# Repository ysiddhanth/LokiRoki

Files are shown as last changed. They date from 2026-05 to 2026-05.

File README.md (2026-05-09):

# LokiRoki

> [!NOTE]
> ## Project Status
>
> ### PCB Build
> - Fabrication completed
> - Components still need to be sent to the assembly company
>
> ### 3D Modeling
> - Initial work has begun
> - Files have not yet been uploaded
>
> ### Programming
> - Awaiting procurement of LoRa modules
> - Firmware testing to begin after hardware arrives

## Application / Problem Statement

Conventional walkie-talkies operate over licensed FM/VHF/UHF bands, which are subject to regulatory constraints, interference from other users, and limited range in urban environments. They are also typically bulky and expensive.

At the same time, consumer-grade Bluetooth and Wi-Fi radios offer only short-range communication and usually require existing infrastructure.

There exists a clear need for a low-cost, long-range, license-free voice communication device suitable for scenarios such as:

- Outdoor activities (hiking, camping, field operations) where cellular coverage is unavailable.
- Campus or community communications without reliance on mobile networks.
- Emergency or off-grid communication links requiring robust, low-power operation.

The proposed device targets ranges of:

- **2–5 km** in urban areas
- **Up to 15 km** in open terrain

The system operates entirely within the **license-exempt 865–868 MHz band in India**.

---

## Proposed Solution

The solution is a self-contained, push-to-talk (PTT) walkie-talkie based on the **LoRa (Long Range)** radio protocol, with onboard speech compression using **Codec 2**.

Two identical units will be built, each capable of:

- Transmitting voice
- Receiving voice
- Operating independently without cellular or internet infrastructure

---

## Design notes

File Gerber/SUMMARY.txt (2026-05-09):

TopCopper:1
BottomCopper:1
TopSolderMask:1
BottomSolderMask:1
TopSilkScreen:1
BottomSilkScreen:1
BoardOutline:1
DrillFile1:1
DrillFile2:1

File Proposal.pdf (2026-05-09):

LoRa Push-to-Talk Walkie Talkie | EE3900 – Project Proposal

# LoRa Push-to-Talk Walkie Talkie

### Project Proposal

Team Members: S A Aravind Eswar (EE24BTECH11053) Siddhanth Y (EE24BTECH11059)

Date: March 2026

### Application / Problem Statement

Conventional walkie-talkies operate over licensed FM/VHF/UHF bands, which are subject to regulatory constraints, interference from other users, and limited range in urban environments. They are also typically bulky and expensive. At the same time, consumergrade Bluetooth and Wi-Fi radios offer short range and require existing infrastructure.

There exists a clear need for a low-cost, long-range, license-free voice communication device suitable for scenarios such as:

- Outdoor activities (hiking, camping, field operations) where cellular coverage is unavailable.
- Campus or community communications without reliance on mobile networks.
- Emergency or off-grid communication links requiring robust, low-power operation.

The proposed device targets ranges of 2–5 km in urban areas and up to 15 km in open terrain, operating entirely within the licence-exempt 865–868 MHz band in India.

### Proposed Solution

The solution is a self-contained, push-to-talk (PTT) walkie-talkie based on the LoRa (Long Range) radio protocol, with onboard speech compression via Codec 2. Two identical units will be built, each capable of transmitting and receiving voice.

System Architecture

The signal chain for transmission is:

Microphone → ESP32 (Codec 2 Encode) → LoRa Module (TX) → Antenna

And for reception:

Antenna → LoRa Module (RX) → ESP32 (Codec 2 Decode) → Class-D Amplifier → Speaker

Key Technology Choices

LoRa Radio – RYLR998 Module
LoRa (Long Range) is a low-power wide-area modulation scheme well suited to battery-operated embedded devices. The RYLR998 operates in the 868/915 MHz band, supports output power up to +22 dBm, and achieves a receive sensitivity of −129 dBm, enabling multi-kilometre links with very modest transmit power. At the Codec 2 bitrates used (450–3200 bps), the available LoRa air-data rate is more than sufficient.

Microcontroller – ESP32-WROOM-32
The ESP32 is a dual-core 240 MHz processor with adequate computational headroom to run real-time Codec 2 encoding and decoding. It communicates with the LoRa module over SPI and with the I2S microphone directly over the I2S bus, eliminating the need for an external ADC.

Speech Codec – Codec 2
Codec 2 is an open-source, low-bitrate speech codec specifically designed for voice over narrow-band radio links. At 1200 bps it produces intelligible speech; at 3200 bps the quality is comparable to FM radio. This drastically reduces the amount of data that must be transmitted over the LoRa link.

Audio Front-End
An I2S MEMS microphone provides digital audio directly to the ESP32 with a 60– 65 dB SNR and no analogue amplification stage. On the output side, a PAM8403 Class-D amplifier (up to 3W into 4 Ω, ∼85% efficient) drives an 8 Ω speaker.

Power System
The PCB design implements a lithium-ion battery management and protection circuit (BQ21040 charger, BQ29700 protection) alongside two TPS6300x buck-boost converters, producing regulated 5 V and 3.3 V rails from the battery. USB-C (USB4085-GF-A receptacle) is used for charging. A CP2102 USB-to-UART bridge enables firmware flashing.

Communication Regulatory Compliance

The device operates in the 865–868 MHz licence-exempt band as defined by WPC India, with transmit power limited to ≤14 dBm to meet CE and regional regulatory requirements, well within the permitted 1W (30 dBm) envelope.

### Practical Feasibility

Component Availability

All components are available through domestic Indian suppliers (primarily robu.in), ensuring short lead times and no import complications. The ESP32-WROOM-32 and PAM8403 are commodity parts stocked by multiple distributors. The RYLR998 LoRa module is a purpose-built transceiver with an AT-command interface, significantly reducing RF development effort.

Cost Effectiveness

The total prototype cost of approximately INR 5000 for one units compares favourably against commercial walkie-talkies with similar range, which typically retail at INR 3,000– 8,000 per unit without the flexibility of open-source firmware or licence-exempt operation.

At scale, the BOM cost would reduce significantly given the commodity nature of most components.

Technical Risk Assessment

Risk | Mitigation | Severity

LoRa bandwidth insufficient for
voice
Codec 2 | compresses | voice | to
<3.2 kbps; | LoRa | supports | up
to 30 kbps

Low

ESP32 too slow for real-time Codec 2 Codec 2 has verified ESP32 ports at 1200–3200 bps

Low

RF regulatory non-compliance | Limit TX power to ≤14 dBm via AT command
Low
Audio latency affecting PTT experi- ence | Codec 2 frame size is 40 ms; accept- able for PTT use
Medium

Table 1: Risk Assessment

Project Timeline

Weeks 1–2: Component procurement and environment setup.
Weeks 3–7: PCB assembly, firmware development, and first prototype testing.
Weeks 8–12: Range testing, design iteration, and final product build. Documentation maintained throughout.

### Competitive Analysis

The table below benchmarks the proposed device against representative products across three market tiers: consumer/budget, mid-range professional, and open-source LoRa alternatives.

Analysis by Tier

Budget tier (INR 2,000–4,000 per pair) – Baofeng UV-5R, Retevis RT22. The Baofeng UV-5R is the dominant budget option globally: inexpensive and capable, but it operates on analogue FM and requires an amateur radio licence to transmit legally in India, making it unsuitable for unlicensed use. The Retevis RT22 is licence-free but limited to short-range analogue UHF with no digital compression, resulting in lower effective range and no path for firmware customisation. Our device enters this tier in cost while significantly outperforming both on range.

Mid-range professional tier (INR 10,000–25,000 per pair) – Motorola XT185. The Motorola XT185 is a polished, IP54-rated PMR446 business radio with up to 24 hours of battery life and a claimed 8 km open-field range. However, in urban conditions its practical range drops to 1–2 km, it is purely analogue, and the pair retails at roughly

Product | TechnologyRange
(Urban /
Open)

Licence
Required

Open
Source

Cost
(pair,
INR )
Our Device (Loki) | LoRa | +
| Codec 2
2–5 km | /
15 km

No (865–
868 MHz
exempt)
Yes | ∼5,600
Baofeng UV-5R | Analogue
FM
VHF/UHF

1–3 km /
5–8 km

Yes (Ham
licence)
No | ∼2,000
Motorola XT185 | Analogue
PMR446

1–2 km /
8 km
No | No | ∼16,000
Retevis RT22 | Analogue
UHF

1–3 km /
5 km
No (licence- free UHF) | No | ∼3,000
LILYGO T3-S3 MVRS | LoRa | +
Codec 2
(dev kit)

2–5 km /
10+ km
No | Yes | ∼4,500
Motorola MOTOTRBO R2 | Digital
DMR
UHF/VHF

3–5 km /
10 km

Yes (business
licence)
No | ∼30,000+

Table 2: Competitive Landscape – representative products across price tiers

INR 16,000–20,000 in India – nearly three times our prototype cost – with no provision for firmware updates or feature extension.

Enterprise tier (INR 30,000+ per pair) – Motorola MOTOTRBO R2. DMR digital radios such as the MOTOTRBO R2 offer superior audio clarity and longer range but mandate a licensed business-band frequency assignment, involve significant recurring regulatory overhead, and are priced far beyond any hobbyist or low-budget deployment scenario.

Open-source LoRa tier – LILYGO T3-S3 MVRS. The LILYGO T3-S3 MVRS is the closest technical analogue to our device: it also uses ESP32 + LoRa + Codec 2 on the same FSK/LoRa modulation at 914.6 MHz. At approximately $27 (INR 2,250) per bare board, two units cost roughly INR 4,500, but the kit ships as a bare development board with no enclosure, no battery management, no charging circuitry, and no push-to-talk hardware – requiring significant additional integration work. Our design integrates all of these elements on a custom PCB.

Key Differentiators

FeatureOur Device Baofeng UV-5R Motorola XT185 LILYGO T3-S3 MOTOTRBO R2

Licence-free
operation
(India)
✓ | × | ✓ | ✓ | ×

Urban
range
>2 km
✓ | ∼ | × | ✓ | ✓

Open-source
firmware
✓ | × | × | ✓ | ×

Integrated
battery
+
USB-C
charging
✓ | × | ✓ | × | ✓

Digital
voice
(noise
resilient)
✓ | × | × | ✓ | ✓

Cost
per
pair
<
INR 8,000
✓ | ✓ | × | ✓ | ×

Productionready
enclosure
– | ✓ | ✓ | × | ✓

Table 3: Feature comparison matrix (✓ = yes, × = no, – = in progress)

In summary, the proposed Loki device occupies a currently vacant position in the market: a licence-free, digitally compressed, long-range, open-source walkie-talkie at a sub-INR 3,000 per-unit cost. No commercially available product combines all four of these attributes simultaneously at this price point.

### Breakdown

Charging

Features current surge protection, smart power switching when charging.

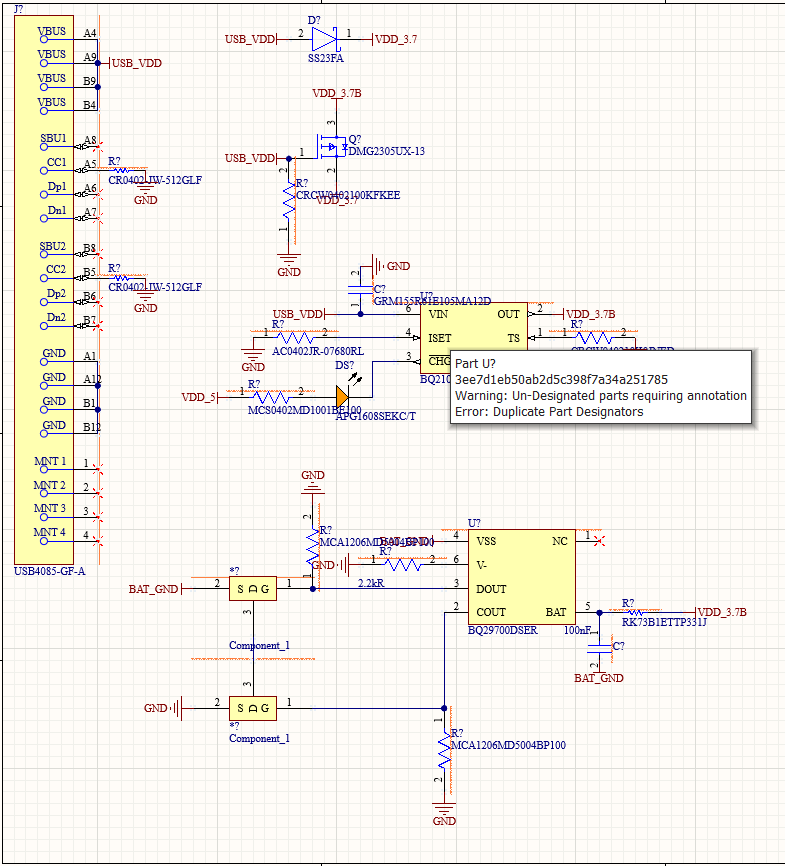
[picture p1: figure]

Uses BQ21040 for charging and BQ29700 for surge protection.

Buck-Boost Converters

Uses Buck-Boost converters for stable constant voltage output.

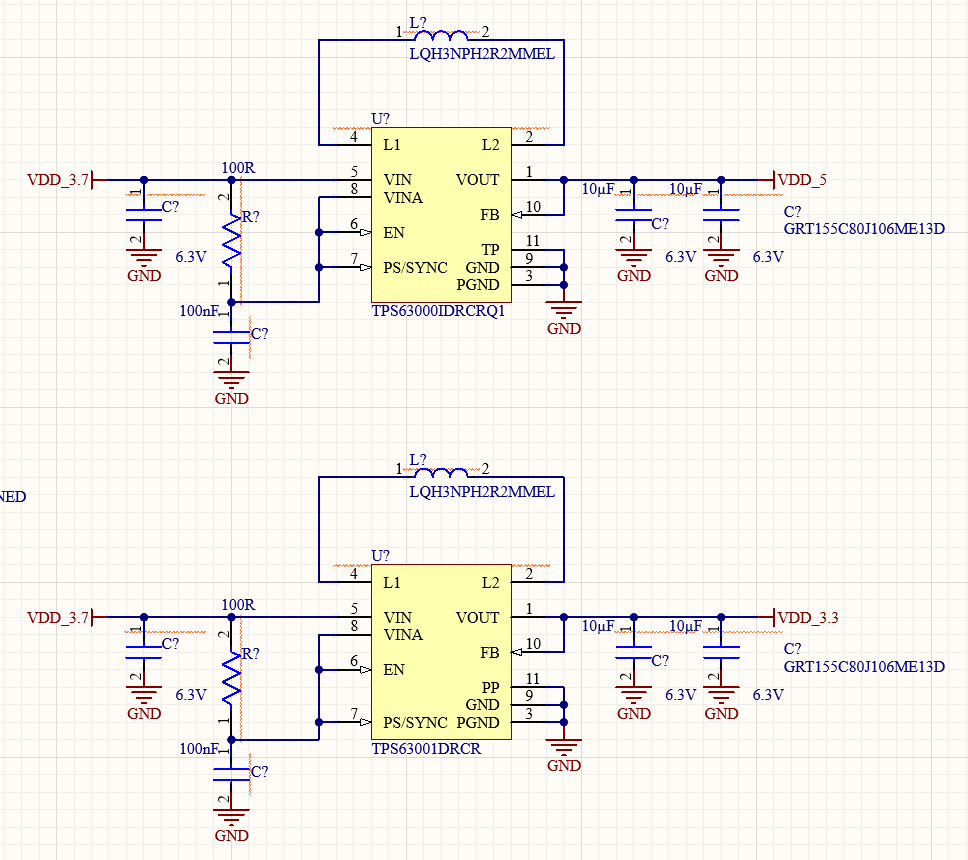
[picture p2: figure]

Figure 1: 5V and 3.3V Buck-Boost converters (top and bottom respectively)

Uses TPS6300X series IC for operation.

### Conclusion

The LoRa PTT walkie-talkie is a technically sound and cost-effective solution to the problem of long-range, infrastructure-independent voice communication. The combination of LoRa’s propagation characteristics, Codec 2’s efficiency, and the ESP32’s processing capability creates a feasible and practical device that can be built entirely from commercially available, domestically sourced components within a modest budget.

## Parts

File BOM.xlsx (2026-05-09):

www.lioncircuits.com No. +91 - 80 4711 2351
Assembly Bill of Materials
PID | 215506
Version | V4.0
Project Name | LokiRoki
Downloaded Date | 2026-05-09 21:12 (IST)
Downloaded By | ee24btech11059@iith.ac.in
Total Line Item | 30
Sl No. | Designator | Description | Quantity | Mpn | Footprint | Value | Assembly Instruction
1 | C102, C104, C105, C106, C108, C109, C202, C203 | CC0402MRX5R5BB106 - YAGEO - MLCC SMD Capacitor - 10 uF, 6.3 V, 0402 [1005 Metric], 20%, X5R, CC Series | 8 | CC0402MRX5R5BB106 | SMD-0402 | 4.53 | N.A
2 | 214, C201, C206, C208, C212, C103, C107, C110 | Yageo 0.1uF 50V 0402 SMD Multilayer Ceramic Capacitor | 8 | Generic | SMD-0402 | 1 | N.A
3 | C204, C205, C210, C211, C213, C101, C111 | 04023D105KAT2A.-KYOCERA AVX-CAP, 1UF, 25V, MLCC, 0402 | 7 | 04023D105KAT2A | SMD-0402 | 3.3 | N.A
4 | R201, R203, R204, R106 | RC0402FR-0710KL-YAGEO-Res Thick Film 0402 10K Ohm 1% 0.063W(1/16W) ±100ppm/°C Pad SMD T/R | 4 | RC0402FR-0710KL | SMD-0402 | 9.38 | N.A
5 | Q201, Q202 | BC817-40W-CBI-SOT-323 Bipolar (BJT) ROHS | 2 | BC817-40W | TO236AB | 3.78 | N.A
6 | Q102, Q103 | N.A | 2 | N.A |  |  | N.A
7 | R107, R108 | RT0402BRD07100RL-YAGEO-Res Thin Film 0402 100 Ohm 0.1% 0.063W(1/16W) ±25ppm/°C Pad SMD T/R | 2 | RT0402BRD07100RL | SMD-0402 | 1.27 | N.A
8 | L101, L102 | SWPA4030S2R2MT-Sunlord-2.2uH 2.95A 20% 39mOhm Shielded Wirewound Power Inductor SMD | 2 | SWPA4030S2R2MT | SMD-1212 | 3.44 | N.A
9 | R110, R112 | Res MC AT Precision Thin Film 1206 5MΩ 0.1% 0.4W ±25ppm/°C Molded Paper T/R | 2 | MCA1206MD5004BP500 | SMD-1206 | 70.33 | N.A
10 | R205, R206, R101, R102 | AC0402FR-075K1L-YAGEO-Res Thick Film 0402 5.1K Ohm 1% 0.063W(1/16W) ±100ppm/°C Pad SMD T/R Automotive AEC-Q20 | 4 | AC0402FR-075K1L | SMD-0402 | 10.31 | N.A
11 | J101, J202 | CONN RCPT USB2.0 TYPE C 24POS RA | 2 | USB4085-GF-A |  | 83.45 | N.A
12 | J201 | Ffc/Fpc Board Connector, Zif, Surface Mount, Plug, 10, Top, 0.5 Mm Rohs Compliant: Yes |Wurth Elektronik 68711014022 | 1 | 68711014022 | 10 Pin FPC Connector | 108.77 | N.A
13 | R104 | 0402WGF6800TCE-Uniohm/Royal-ohm-62.5mW Thick Film Resistors 50V ±100ppm/℃ ±1% 680Ω 0402 Chip Resistor - Surface Mount ROHS | 1 | 0402WGF6800TCE | SMD-0402 | 0.06 | N.A
14 | DS102 | 19-217/G7C-AN1P2/3T-EVERLIGHT-Yellow-Green 574nm LED Indication - Discrete 2V 0603 (1608 Metric) | 1 | 19-217/G7C-AN1P2/3T-EVERLIGHT LED | SMD-0603 | 1 | N.A
15 | U101 | IC BATT CHG LI-ION 1CELL SOT23-6 | 1 | BQ21040DBVR | SOT23-6 | 83.45 | N.A
16 | U104 | IC LITHIUM BATT PROTECT 6-SON | 1 | BQ29700DSER | 6-SON | 5.4 | N.A
17 | U202 | Single-Chip USB to URAT Bridge, 3.3 V, -40 to 85 degC, 28-Pin QFN, RoHS, Tape and Reel | 1 | CP2102-GMR | 28-Pin QFN | 832.66 | N.A
18 | R103 | RC0402FR-07100KL,YAGEO,100 kOhm ±1% 0.063W, 1/16W Chip Resistor 0402 | 1 | RC0402FR-07100KL | SMD-0402 | 0.09 | N.A
19 | Q101 | MOSFET P-CH 20V 4.2A SOT23 | 1 | DMG2305UX-13 | SOT23 | 11 | N.A
20 | MD201 | RX TXRX MOD WIFI SURFACE MOUNT | 1 | ESP32-WROOM-32 |  |  | N.A
21 | C207 | IM02B473K100NT-FH-SMD Multilayer Ceramic Capacitor, 47000 pF(4.7nF), 10 V, 0402 [1005 Metric], ± 10%, X7R | 1 | IM02B473K100NT | SMD-0402 | 9.38 | N.A
22 | C209 | GRT155R71A474KE01D-Murata-Cap Ceramic 0.47uF 10V X7R 10% Pad SMD 0402 125°C Automotive T/R | 1 | GRT155R71A474KE01D | SMD-0402 | 9.38 | N.A
23 | R105 | RC0402FR-071K2L-YAGEO-Res Thick Film 0402 1.2K Ohm 1% 0.063W(1/16W) ±100ppm/°C Pad SMD T/R | 1 | RC0402FR-071K2L | SMD-0402 | 0.08 | N.A
24 | U201 | IC AMP CLASS D STEREO 3W 16SOP | 1 | PAM8403DR | 16-SOIC | 67.51 | N.A
25 | R109 | AC0402FR-072K2L-YAGEO-Res Thick Film 0402 2.2K Ohm 1% 0.063W(1/16W) ±100ppm/°C Pad SMD T/R Automotive AEC-Q200 | 1 | AC0402FR-072K2L | SMD-0402 | 0.07501 | N.A
26 | R111 | CRCW0402330RFKED-VISHAY-SMD Chip Resistor, 330 ohm, ± 1%, 62.5 mW, 0402 [1005 Metric], Thick Film, General Purpose | 1 | CRCW0402330RFKED | SMD-0402 | 0.37 | N.A
27 | R207 | 0402WGJ0470TCE-Uniohm/Royal-ohm-62.5mW Thick Film Resistors 50V±100ppm/℃ ±5% 47Ω 0402 Chip Resistor - Surface Mount ROHS | 1 | 0402WGJ0470TCE | SMD-0402 | 0.03 | N.A
28 | DS101 | NRVBSS34FA Schottky Barrier Rectifier Diode 40V 3A 2-Pin SOD−123FL T/R | 1 | SS34FA | SOD-123FL-2 | 49 | N.A
29 | U102 | Buck-Boost Voltage Converter with 1.8 to 5.5 V Input and 1.2 to 5.5 V Output, -40 to 85 degC, 10-Pin SON (DRC), Green (RoHS & no Sb/Br) | 1 | TPS63000IDRCRQ1 | 10-VFDFN Exposed Pad | 136.06 | N.A
30 | U103 | Buck-Boost Voltage Converter with 1.8 to 5.5 V Input and 3.3 V Output, -40 to 85 degC, 10-Pin SON (DRC), Green (RoHS & no Sb/Br) | 1 | TPS63001DRCR | 10-VFDFN Exposed Pad | 225.89 | N.A

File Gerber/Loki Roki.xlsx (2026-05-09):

Line # | Name | Description | Designator | Revision ID | Revision Status | Quantity | Manufacturer 1 | Manufacturer Part Number 1 | Manufacturer Lifecycle 1 | Supplier 1 | Supplier Part Number 1 | Supplier Unit Price 1 | Supplier Subtotal 1
 | GRT155C80J106ME13D | GRT155C80J106ME13D Multilayer Ceramic Capacitors MLCC - SMD/SMT 0402 10uF 6.3VDC 20% X6S AEC-Q200 | C102, C104, C105, C106, C108, C109 | CMP-00260-136148754-1 | Up to date | 6 | Murata | GRT155C80J106ME13D | Volume Production | DigiKey | 490-GRT155C80J106ME13DCT-ND | 14.82 | 148.15
 | C0402C104K8RAC | C0402 0.10 μF X7R 10.00% 10 V | 214, C201, C206, C208, C212 | CMP-03020-004693-2 | Up to date | 5 | Yageo Group | C0402C104K8RAC | Volume Production | Mouser | 80-C0402C104K8RAC | 0.56261 | 5626.07
 | GRM155C81C105ME11J | Chip Multilayer Ceramic Capacitors for General Purpose, 0402, 1.0uF, X6S, 22%, 20%, 16V | C204, C205, C210, C211, C213 | CMP-06035-050604-1 | Up to date | 5 | Murata | GRM155C81C105ME11J | Volume Production | Mouser | 81-GRM155C81C105ME1J | 3.75 | 37.51
 | 560112110006 | Res, 10K, 5%, 0.1W, Thick Film, 0402 Rohs Compliant: Yes | R201, R203, R204 | CMP-03913-145532690-1 | Up to date | 3 | Wurth Elektronik | 560112110006 | Unknown | Mouser | 710-560112110006 | 9.38 | 28.13
 | GRM155R71H104ME14D | Chip Multilayer Ceramic Capacitors for General Purpose, 0402, 0.10uF, X7R, 15%, 20%, 50V | C103, C107, C110 | CMP-06035-043433-1 | Up to date | 3 | Murata | GRM155R71H104ME14D | Volume Production | Mouser | 81-GRM155R71H104ME4D | 1.5 | 15
 | BC817,215 | TRANS NPN 45V 500MA TO236AB | Q201, Q202 | CMP-14406-000041-1 | Up to date | 2 | Nexperia | BC817,215 | Volume Production | DigiKey | 1727-4844-1-ND | 10.31 | 20.63
 | Component_1 |  | Q102, Q103 |  |  | 2
 | CR0402-JW-512GLF |  | R101, R102 | CMP-1011-00091-2 | Up to date | 2 | Bourns | CR0402-JW-512GLF | Volume Production | Newark | CR0402-JW-512GLF | 0.09377 | 0.18754
 | CRCW0402100RFKED | RES Thick Film, 100Ω, 1%, 0.063W, 100ppm/°C, 0402 | R107, R108 | CMP-1011-00397-3 | Up to date | 2 | Bourns | CR0402-FX-1000GLF | Volume Production | Newark | CR0402-FX-1000GLF | 0.18754 | 0.37507
 | GRM155R61E105MA12D | Chip Multilayer Ceramic Capacitors for General Purpose, 0402, 1.0uF, X5R, 15%, 20%, 25V | C101, C111 | CMP-06035-012395-1 | Up to date | 2 | Murata | GRM155R61E105MA12D | Volume Production | DigiKey | 490-10018-6-ND | 9.38 | 18.75
 | LQH3NPH2R2MMEL | Wire Wound Ferrite Inductor for Power Lines For Automotive 2.2μH ±20% 0.078Ω 2100mA 1212 | L101, L102 | CMP-06042-006723-1 | Up to date | 2 | Murata | LQH3NPH2R2MMEL | New Product | Mouser | 81-LQH3NPH2R2MMEL | 34.69 | 69.39
 | MCA1206MD5004BP100 | Res MC AT Precision Thin Film 1206 5MΩ 0.1% 0.4W ±25ppm/°C Molded Paper T/R | R110, R112 | CMP-02407-011229-1 | Up to date | 2 | Vishay | MCA1206MD5004BP100 | Volume Production | Mouser | 594-MCA1206MD5004BP1 | 70.33 | 140.65
 | RN73R1JTTD5101B25 | RN73R1JTTD5101B25 Res, 5K1, 0.1%, 0.1W, 0603 Rohs Compliant: Yes |Koa RN73R1JTTD5101B25 | R205, R206 | CMP-00683-99548008-1 | Up to date | 2 | KOA Speer | RN73R1JTTD5101B25 | Volume Production | Mouser | 660-RN73R1JTD5101B25 | 10.31 | 20.63
 | USB4085-GF-A | CONN RCPT USB2.0 TYPE C 24POS RA | J101, J202 | CMP-196119-000001-2 | Up to date | 2 | Global Connector Technology | USB4085-GF-A | Volume Production | DigiKey | 2073-USB4085-GF-ADKR-ND | 83.45 | 166.91
 | ZRB15XC80J106ME05D | CAP CERAMIC MULTILAYER 10UF 6.3V | C202, C203 | CMP-06035-000026-1 | Up to date | 2 | Murata | ZRB15XC80J106ME05D | Volume Production
 | 68711014022 | Ffc/Fpc Board Connector, Zif, Surface Mount, Plug, 10, Top, 0.5 Mm Rohs Compliant: Yes |Wurth Elektronik 68711014022 | J201 | CMP-1502-01551-3 | Up to date | 1 | Wurth Elektronik | 68711014022 | Unknown | DigiKey | 732-2020-1-ND | 108.77 | 108.77
 | AC0402JR-07680RL | RES 680Ω ±5% 0.063W 0402 | R104 | CMP-03412-038007-1 | Up to date | 1 | Yageo Group | AC0402JR-07680RL | Volume Production | Farnell | AC0402JR-07680RL | 0.37763 | 3.78
 | APG1608SEKC/T | LED, SMT, 0603(1608), 0.25mm Tthickness, Super Bright Orange | DS102 | CMP-0239-00002-1 | Up to date | 1 | Kingbright | APG1608SEKC/T | Volume Production | Arrow Electronics | APG1608SEKC/T | 1 | 1
 | BQ21040DBVR | IC BATT CHG LI-ION 1CELL SOT23-6 | U101 | CMP-04911-000045-1 | Up to date | 1 | Texas Instruments | BQ21040DBVR | Volume Production | DigiKey | 296-47315-1-ND | 83.45 | 83.45
 | BQ29700DSER | IC LITHIUM BATT PROTECT 6-SON | U104 | CMP-04911-000043-1 | Up to date | 1 | Texas Instruments | BQ29700DSER | Volume Production | Arrow Electronics | BQ29700DSER | 5.4 | 5.4
 | CP2102-GMR | Single-Chip USB to URAT Bridge, 3.3 V, -40 to 85 degC, 28-Pin QFN, RoHS, Tape and Reel | U202 | CMP-2000-04924-1 | Up to date | 1 | Silicon Lab | CP2102-GMR | Volume Production | Mouser | 634-CP2102-GMR | 832.66 | 832.66
 | CRCW040210K0JNED | RES Thick Film, 10kΩ, 5%, 0.063W, 200ppm/°C, 0402 | R106 | CMP-2002-08136-3 | Up to date | 1 | Vishay | CRCW040210K0JNED | Volume Production | DigiKey | 541-10KJCT-ND | 9.38 | 9.38
 | CRCW0402100KFKEE | RES Thick Film, 100kΩ, 1%, 0.063W, 100ppm/°C, 0402 | R103 | CMP-02407-010357-1 | Up to date | 1 | Vishay | CRCW0402100KFKEE | Volume Production | Newark | CRCW0402100KFKEE | 0.2813 | 0.2813
 | DMG2305UX-13 | MOSFET P-CH 20V 4.2A SOT23 | Q101 | CMP-12801-000021-1 | Up to date | 1 | Diodes Inc. | DMG2305UX-13 | Volume Production | Newark | DMG2305UX-13 | 3.38 | 3.38
 | ESP32-WROOM-32 | RX TXRX MOD WIFI SURFACE MOUNT | MD201 | CMP-194065-000008-1 | Up to date | 1 | Espressif Systems | ESP32-WROOM-32 | Unknown
 | GRM155R71H472JA01J | Chip Multilayer Ceramic Capacitors for General Purpose, 0402, 4700pF, X7R, 15%, 5%, 50V | C207 | CMP-06035-057424-1 | Up to date | 1 | Murata | GRM155R71H472JA01J | Volume Production | Mouser | 81-GRM155R71H472JA1J | 9.38 | 9.38
 | JMK105B7474KV-F | None | C209 | CMP-14477-003885-2 | Up to date | 1 | TAIYO YUDEN | JMK105B7474KV-F | Volume Production | Mouser | 963-JMK105B7474KV-F | 9.38 | 9.38
 | MCS0402MD1001BE100 | RES SMD 1.2K OHM 1% 1/10W 0402 | R105 | CMP-02407-000781-1 | Up to date | 1 | Vishay | MCS0402MD1001BE100 | Volume Production | Arrow Electronics | MCS0402MD1001BE100 | 7.09 | 7.09
 | PAM8403DR | IC AMP CLASS D STEREO 3W 16SOP | U201 | CMP-12733-000001-1 | Up to date | 1 | Diodes Inc. | PAM8403DR | End of Life | Mouser | 621-PAM8403DR | 67.51 | 67.51
 | RC1005J222CS | Res Thick Film 0402 2.2kΩ 5% 0.063W ±100ppm/°C Molded SMD T/R | R109 | CMP-13261-003558-1 | Up to date | 1 | Samsung Electro-Mechanics | RC1005J222CS | Volume Production | Arrow Electronics | RC1005J222CS | 0.07501 | 0.07501
 | RK73B1ETTP331J |  | R111 | CMP-2002-03763-1 | Up to date | 1 | KOA Speer | RK73B1ETTP331J | Volume Production | DigiKey | 2019-RK73B1ETTP331JCT-ND | 9.38 | 9.38
 | RMCF0402JT47R0 | 47Ω ±5% 0.063W 0402 Thick Film Chip Resistor AEC-Q200 compliant | R207 | CMP-26527-002982-1 | Up to date | 1 | Stackpole Electronics | RMCF0402JT47R0 | Volume Production | Arrow Electronics | RMCF0402JT47R0 | 9.36 | 9.36
 | SS23FA | SS23FA 2 A, 30 V Surface Mount Schottky Barrier Rectifiers | DS101 | CMP-00278-84331614-1 | Up to date | 1 | onsemi | SS23FA | Volume Production | Arrow Electronics | SS23FA | 5.41 | 5.41
 | TMM-110-01-L-D | CONN HEADER VERT 20POS 2MM | J203 | CMP-02766-001520-1 | Up to date | 1 | Samtec | TMM-110-01-L-D | Volume Production | Avnet | TMM-110-01-L-D | 185.62 | 185.62
 | TPS63000IDRCRQ1 | Buck-Boost Voltage Converter with 1.8 to 5.5 V Input and 1.2 to 5.5 V Output, -40 to 85 degC, 10-Pin SON (DRC), Green (RoHS & no Sb/Br) | U102 | CMP-0349-00004-2 | Up to date | 1 | Texas Instruments | TPS63000IDRCRQ1 | Volume Production | Arrow Electronics | TPS63000IDRCRQ1 | 136.06 | 136.06
 | TPS63001DRCR | Buck-Boost Voltage Converter with 1.8 to 5.5 V Input and 3.3 V Output, -40 to 85 degC, 10-Pin SON (DRC), Green (RoHS & no Sb/Br) | U103 | CMP-0345-00006-2 | Up to date | 1 | Texas Instruments | TPS63001DRCR | Volume Production | Arrow Electronics | TPS63001DRCR | 225.89 | 225.89
